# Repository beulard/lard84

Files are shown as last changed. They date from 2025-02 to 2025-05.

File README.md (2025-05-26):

# lard84

A custom 75% ansi low-profile keyboard.

- [PCB](#pcb)
- [Plate](#plate)
- [Case](#case)
- [Acknowledgments](#acknowledgments)
- [Extra pictures](#extra-pictures)

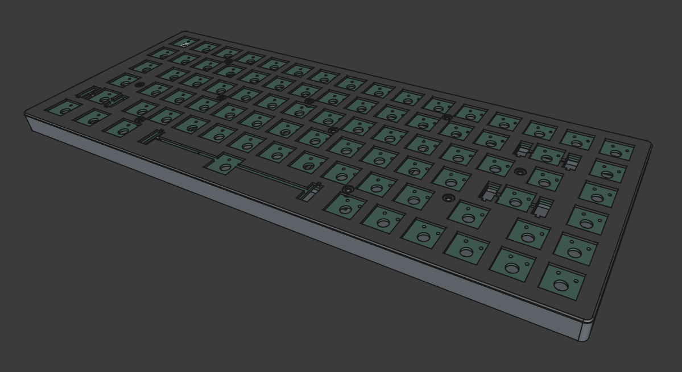
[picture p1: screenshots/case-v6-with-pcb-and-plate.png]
Case, PCB and plate assembled


The assembly is done in (sort of) [sandwich mount style](https://thomasbaart.nl/2019/04/07/cheat-sheet-custom-keyboard-mounting-styles/).
Compared to sandwich mount, there is no top frame (the plate sits at the top), and
it is screwed into the case's mounting posts from above.

Here it is finally assembled:
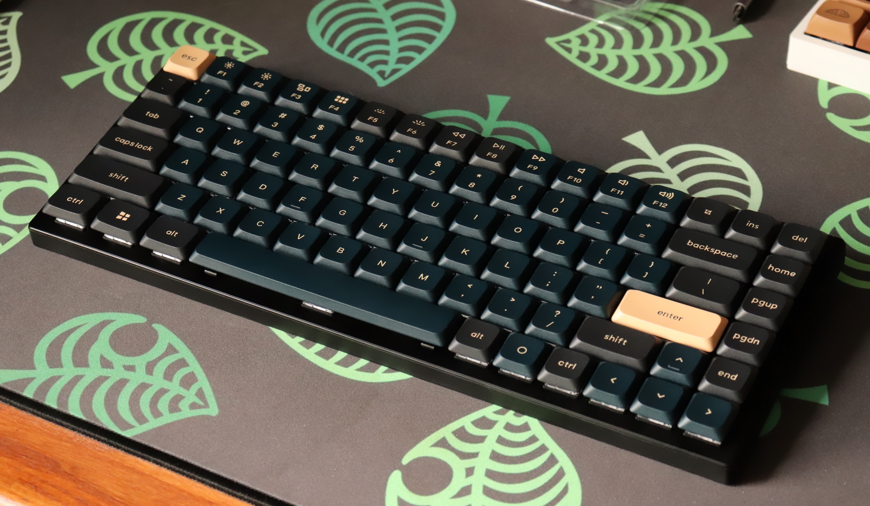
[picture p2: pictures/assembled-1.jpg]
The lard84 fully assembled


## PCB

The PCB (lard84.kicad_pro) is an 84-key design based on the [RP2350 Stamp](https://lectronz.com/products/rp2350-stamp), made using KiCad 8.0.
It is entirely hand-solderable (smallest footprint is 0603).

The design features a micro-usb port, full n-key rollover using a diode for each switch, a status LED, and apparent debug pins for development.

Key placement follows an [ANSI 75% layout](https://docs.keebd.com/information/keyboard-layouts#75-ansi).

The design supports [Gateron KS-33 low-profile switches](https://www.gateron.co/products/gateron-low-profile-mechanical-switch-set), and features holes
for the associated [low-profile stabilizers](https://www.gateron.com/products/gateron-low-profile-plate-mounted-stabilizer).

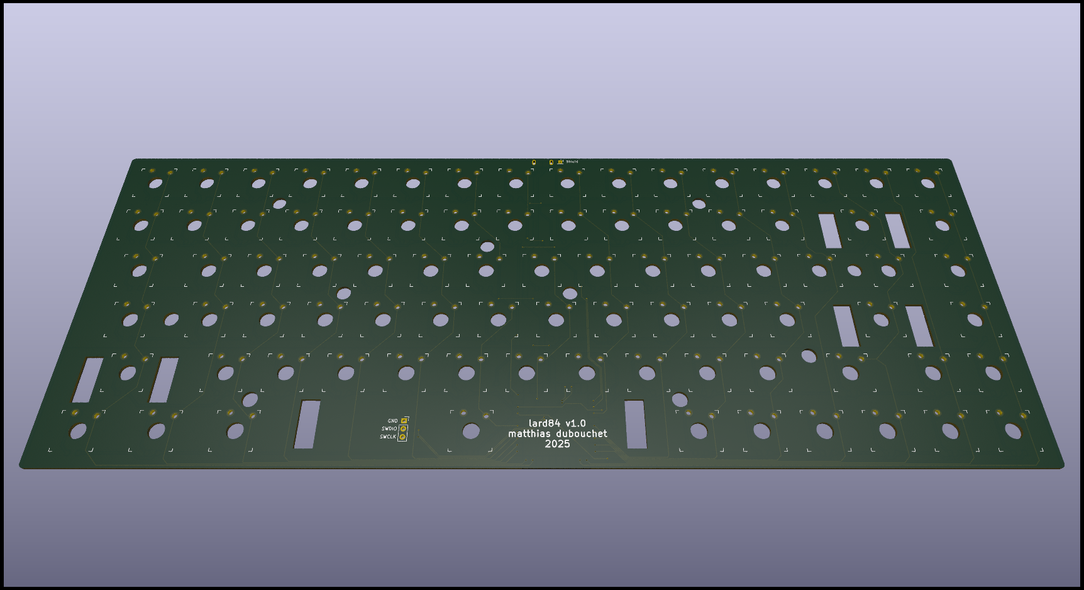
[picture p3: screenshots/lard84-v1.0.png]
A screenshot of the PCB in KiCad

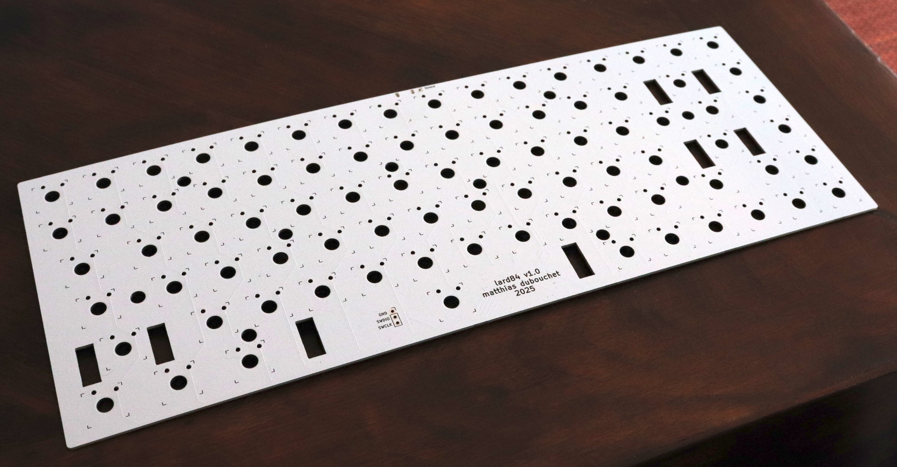
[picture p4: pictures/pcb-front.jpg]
PCB irl


## Plate

The top plate (plate v38.f3z) supports the switches, adds rigidity and gives a nice finish. It was made in Fusion360.

It is a relatively simple design with a square cutout for each key, two extra cutouts around the Backspace, Space, Enter and LShift keys
for their plate-mounted stabilizers, and 10 mounting holes for screws.

One key challenge was to figure out the placement and shape for the stabilizer cutouts, because of insufficient information on
the datasheets from the manufacturer.

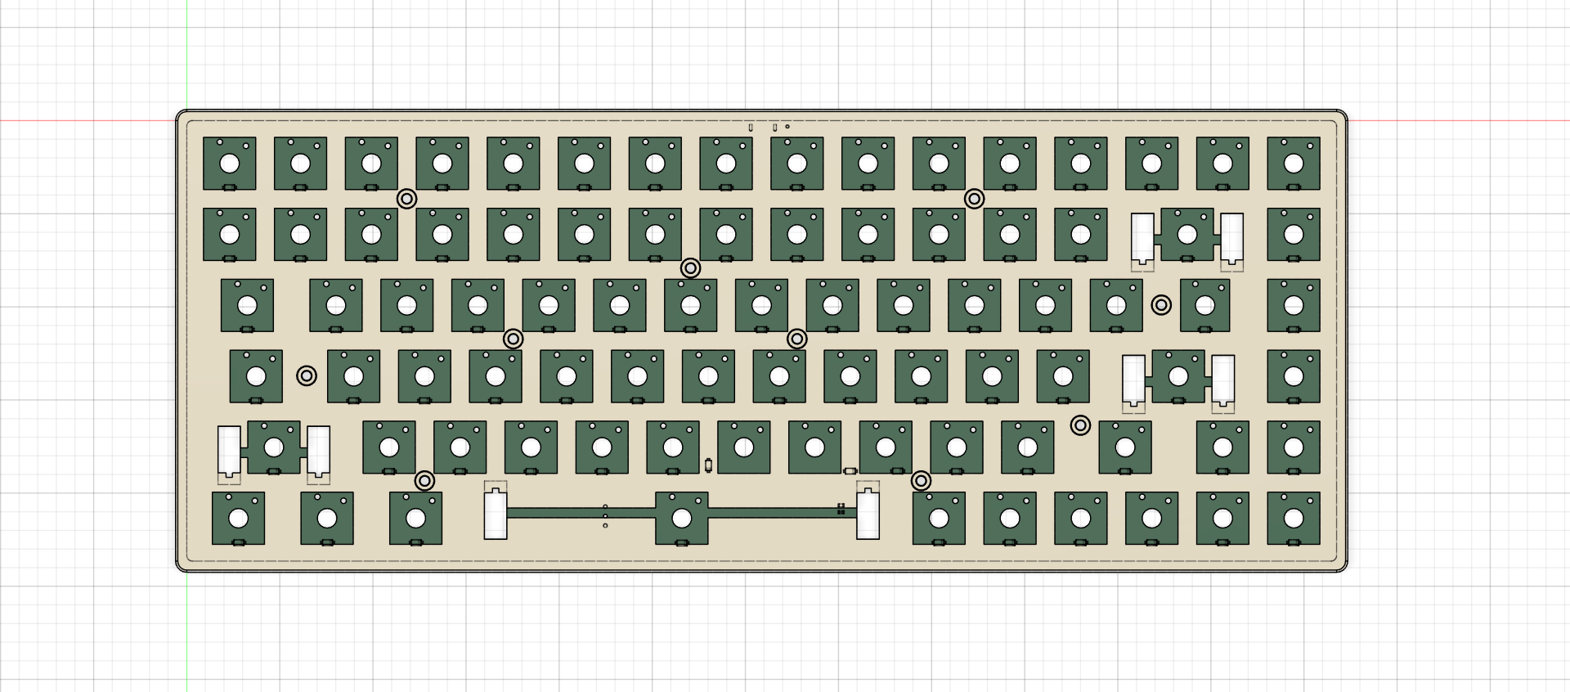
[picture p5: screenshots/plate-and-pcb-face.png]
Plate in Fusion360

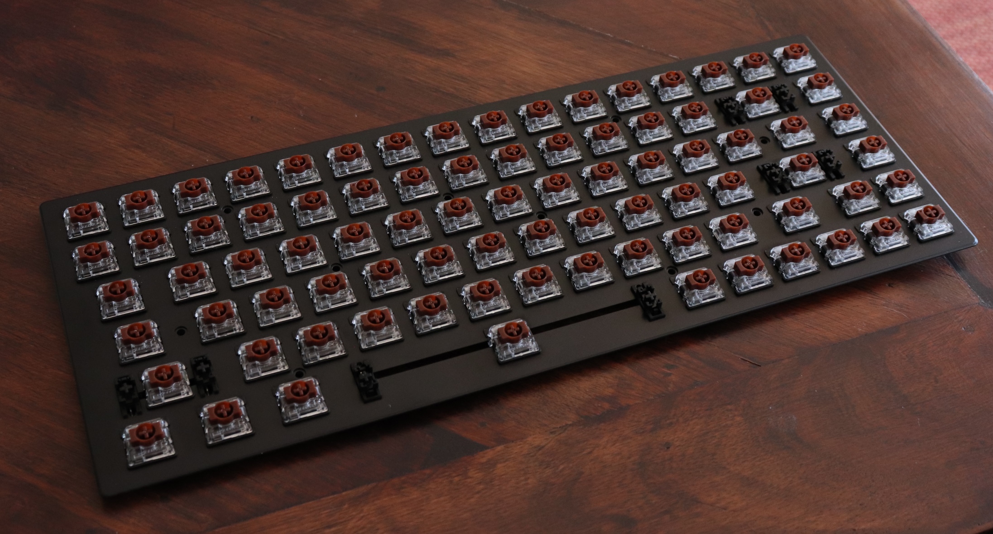
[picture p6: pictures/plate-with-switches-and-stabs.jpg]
Plate irl


## Case

The case (case.FCStd) is a 3D-printable plastic enclosing and two feet for a more comfortable typing angle.

The enclosing features mounting posts for the PCB and plate, and anti-warping structural elements.

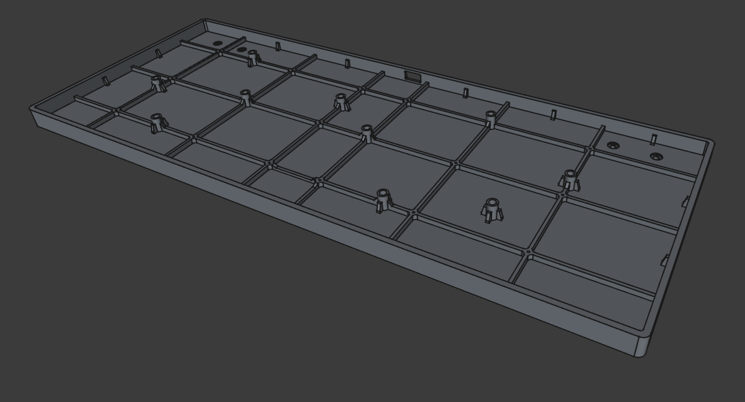
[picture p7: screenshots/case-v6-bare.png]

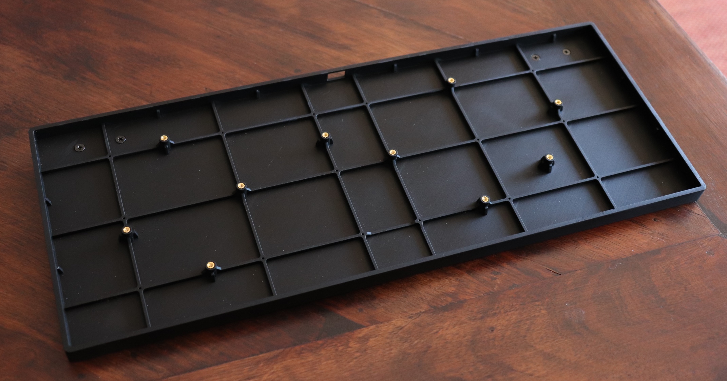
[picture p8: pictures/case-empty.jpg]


## Acknowledgments

Thanks to these open source repos for providing vital KiCad symbol/footprint libraries.
- [RP2350 Stamp](https://github.com/solderparty/rp2xxx_stamp_footprints)
- [Gateron switches](https://github.com/siderakb/key-switches.pretty)

## Extra pictures

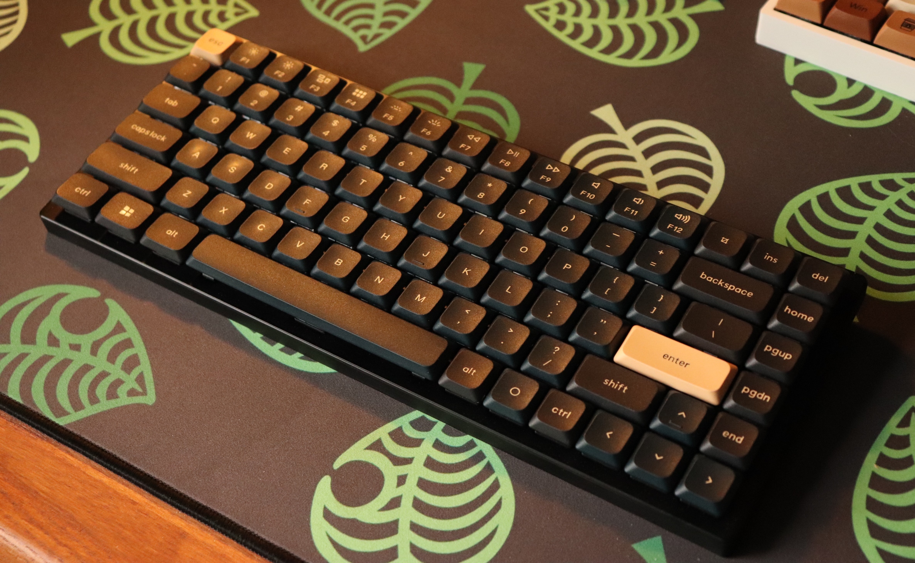
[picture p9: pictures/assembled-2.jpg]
Another assembled pic

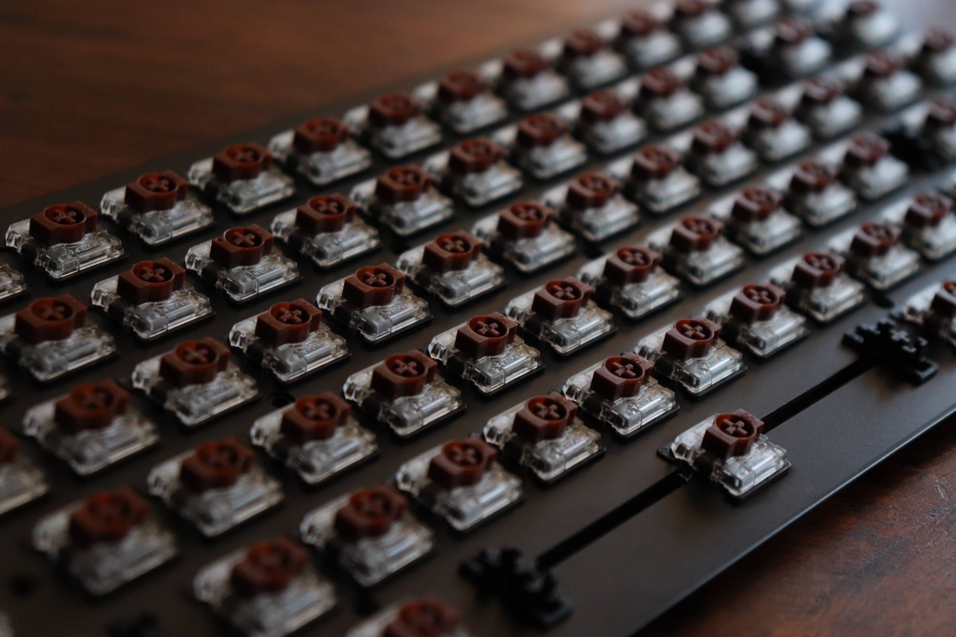
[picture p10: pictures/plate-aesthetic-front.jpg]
Front of plates

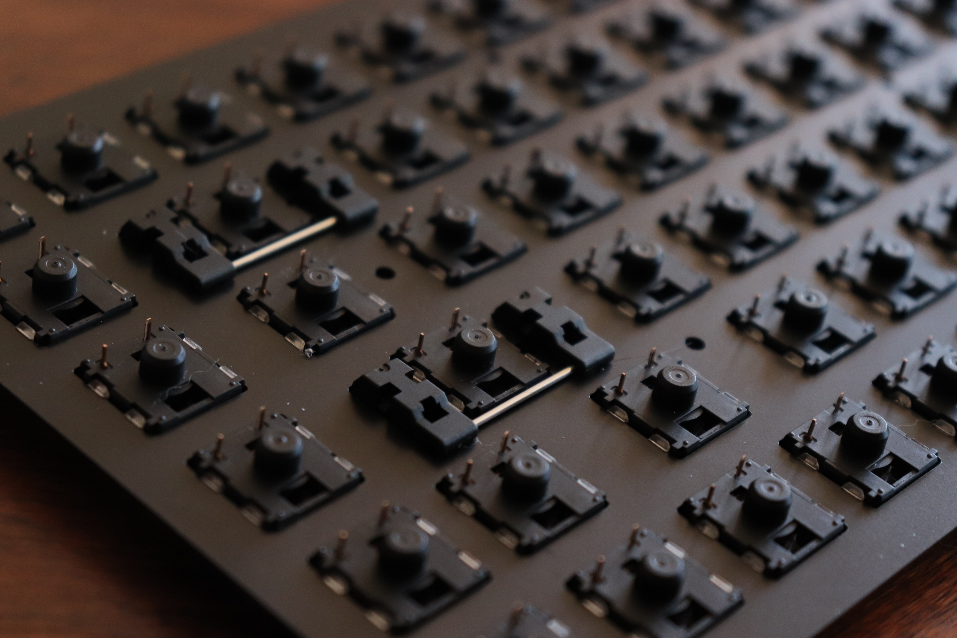
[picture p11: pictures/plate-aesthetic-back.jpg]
Back of plate

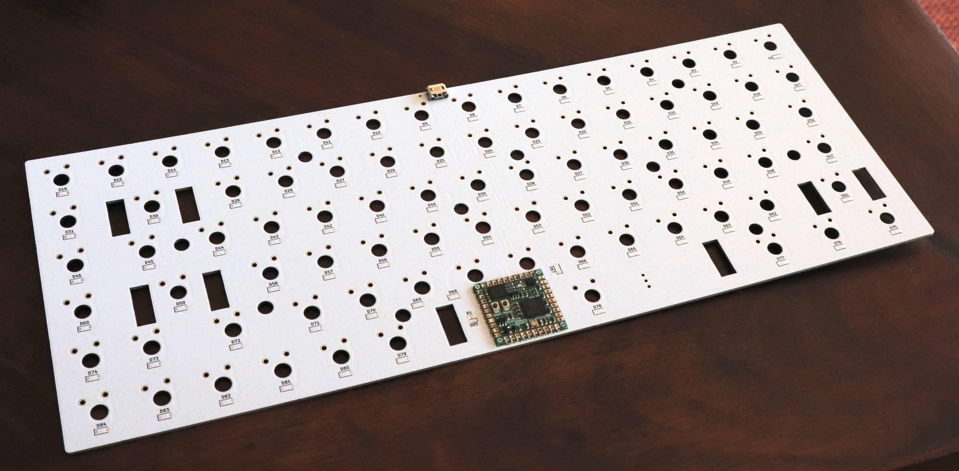
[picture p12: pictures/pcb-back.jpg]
PCB back

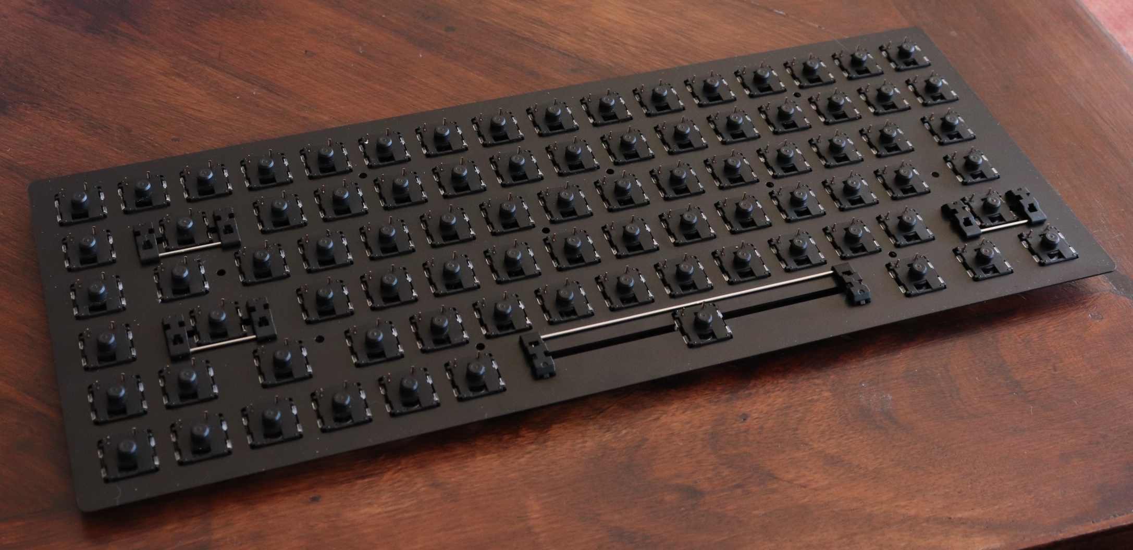
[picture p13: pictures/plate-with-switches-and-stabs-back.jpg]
Plate back

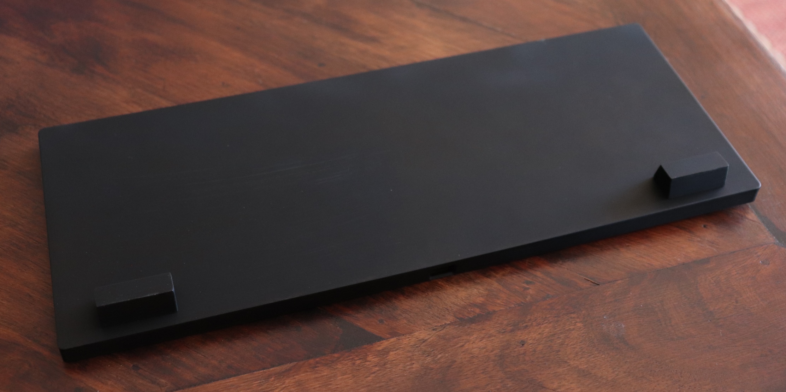
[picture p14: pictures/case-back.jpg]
Back of case with feet


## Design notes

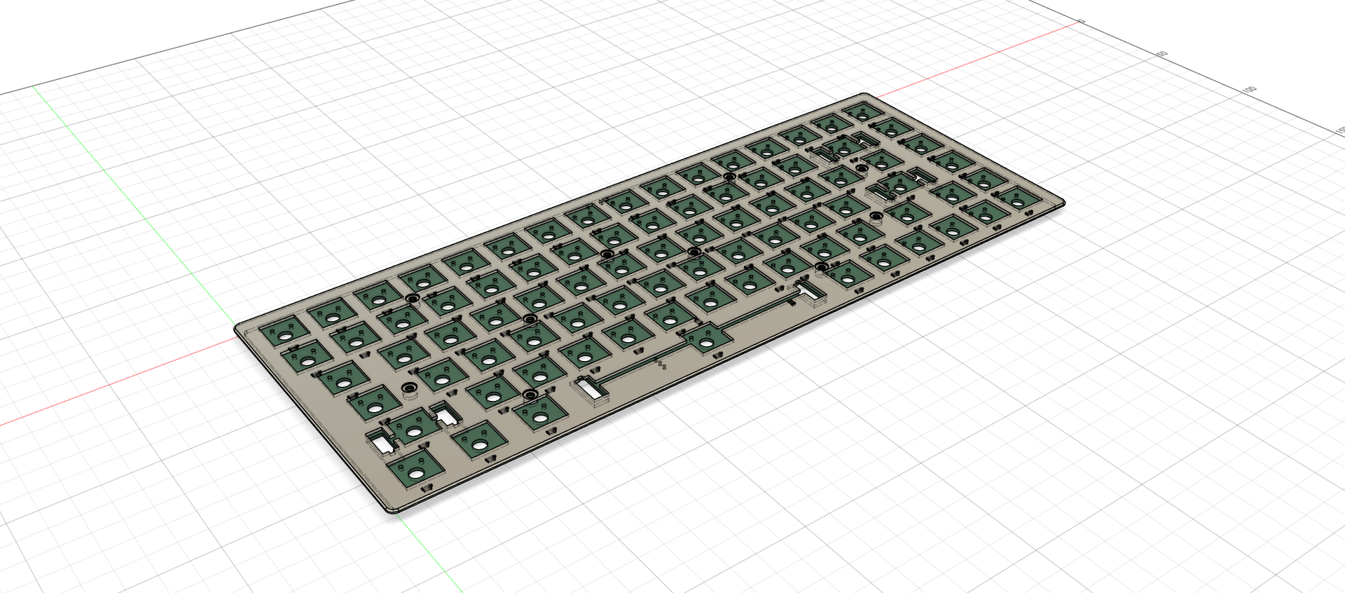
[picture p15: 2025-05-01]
screenshots/plate-and-pcb.png

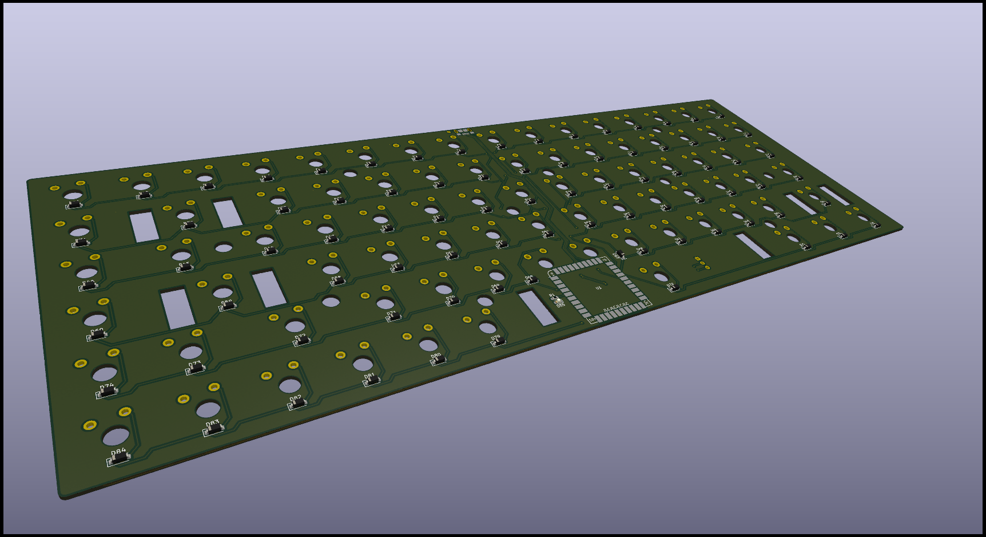
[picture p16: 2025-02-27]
screenshots/lard84-v1.0-angle-back.png

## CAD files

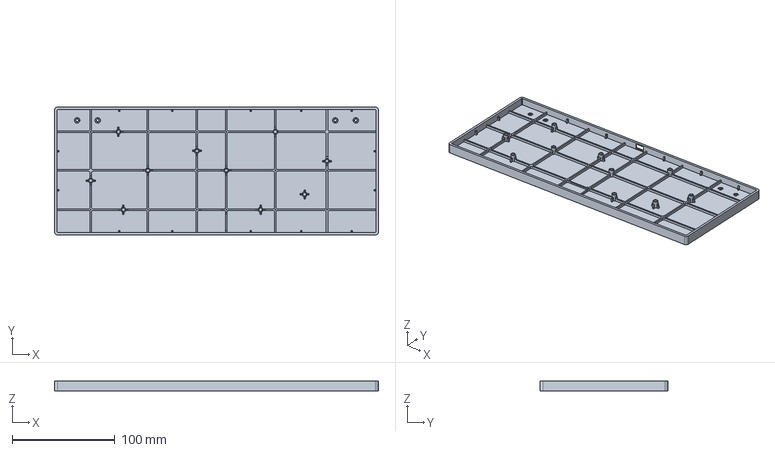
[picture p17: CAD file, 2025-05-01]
case.FCStd
314.7 x 124.3 x 10.0 mm

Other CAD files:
plate v38.f3z

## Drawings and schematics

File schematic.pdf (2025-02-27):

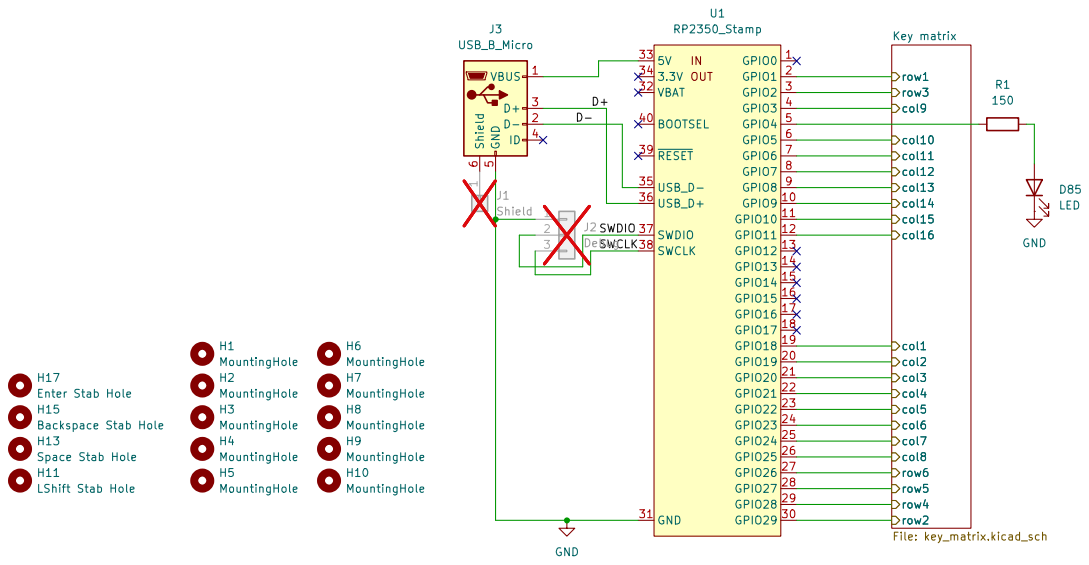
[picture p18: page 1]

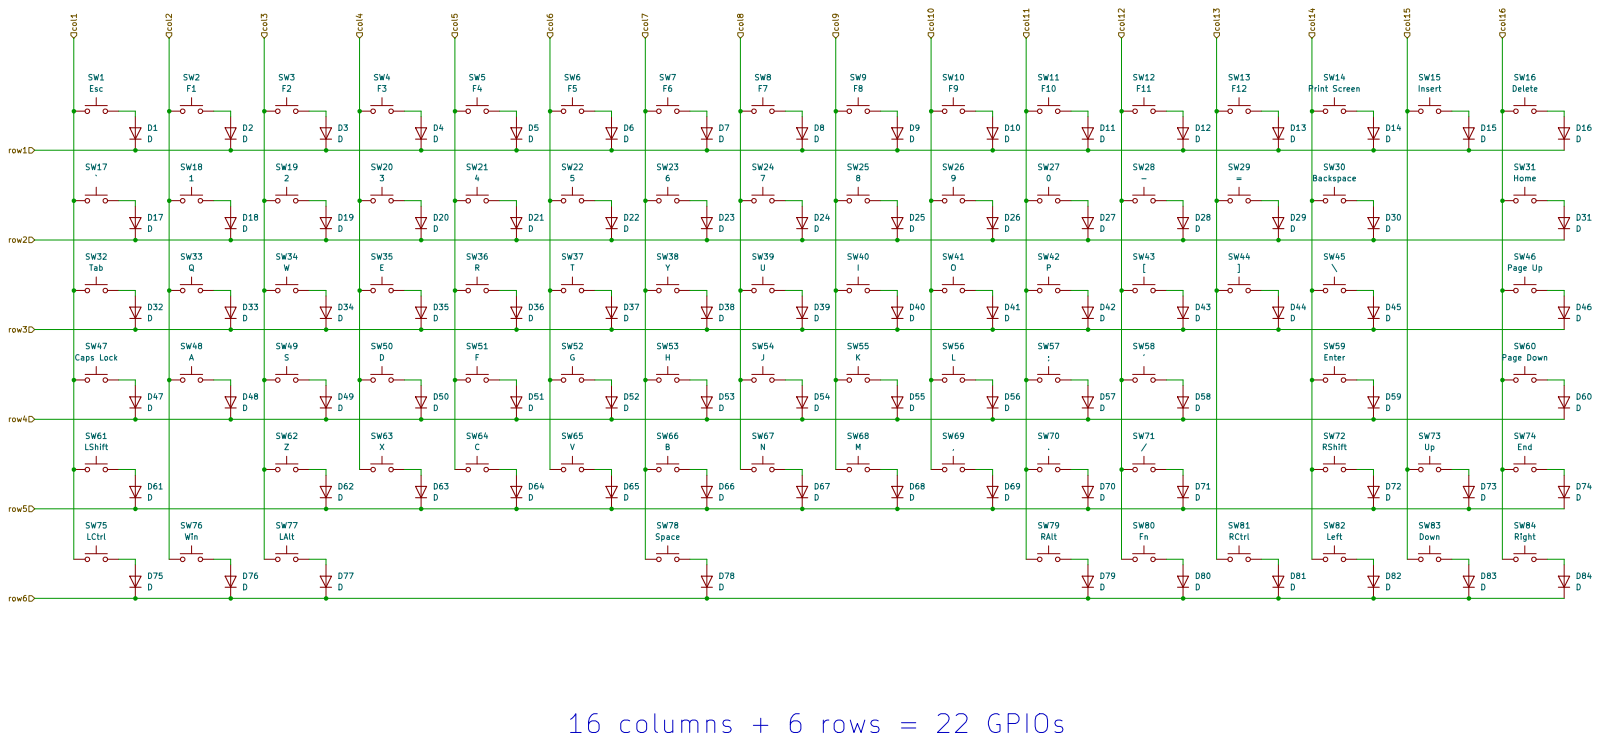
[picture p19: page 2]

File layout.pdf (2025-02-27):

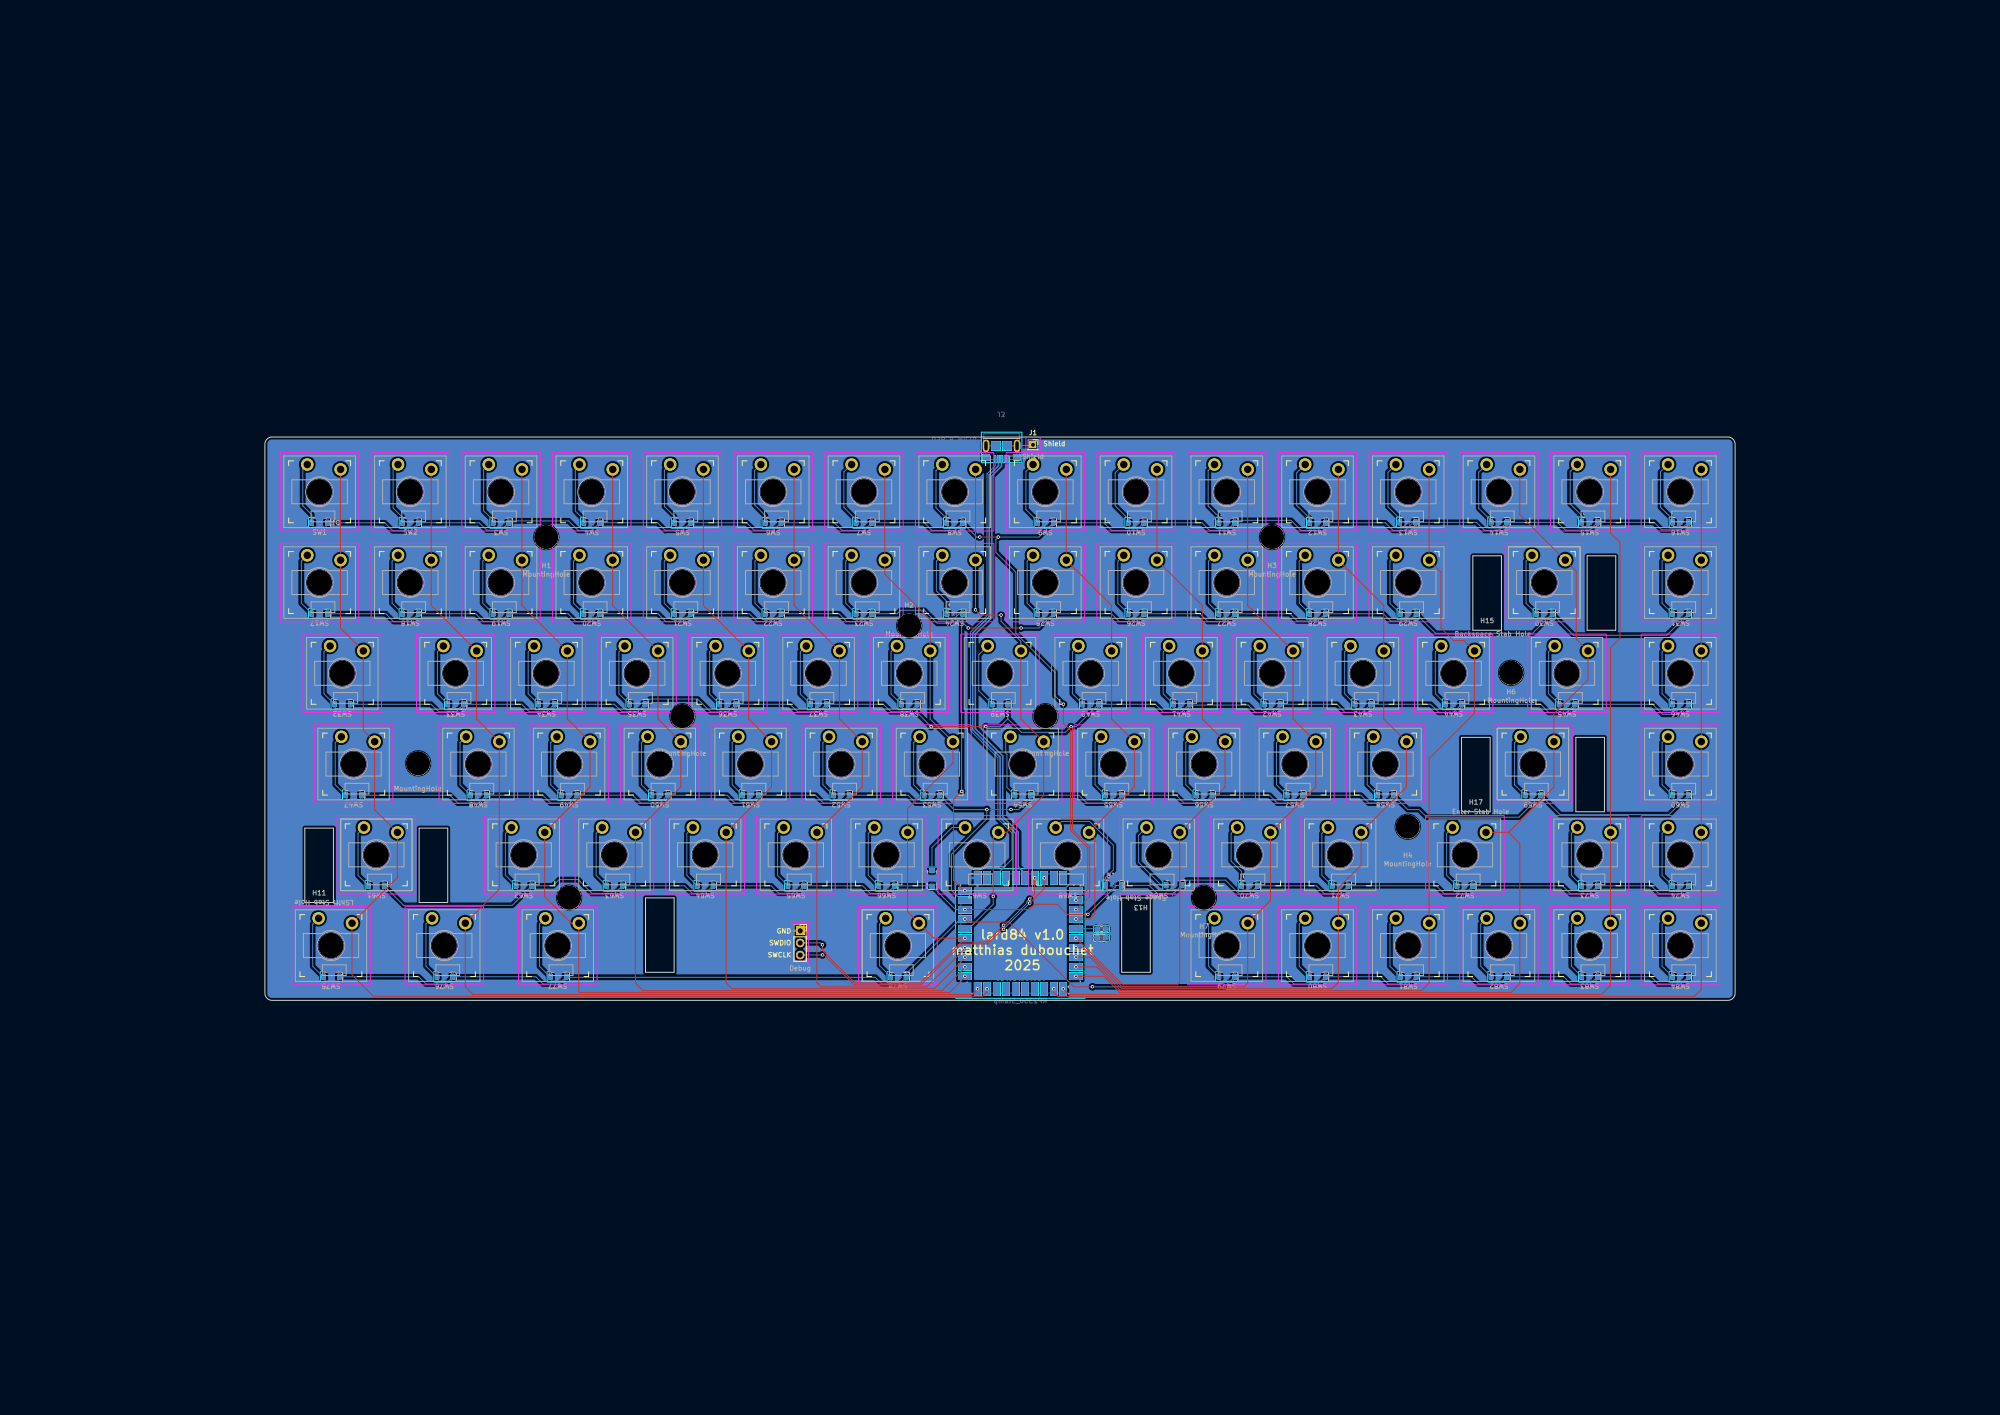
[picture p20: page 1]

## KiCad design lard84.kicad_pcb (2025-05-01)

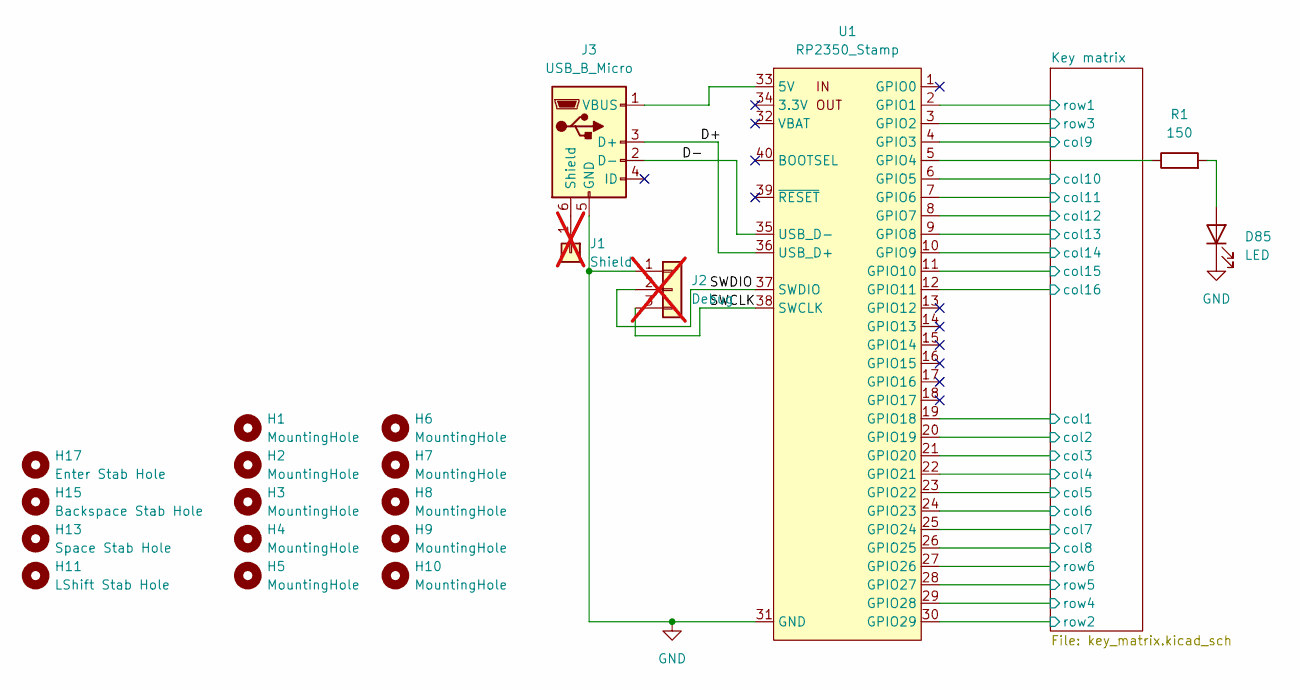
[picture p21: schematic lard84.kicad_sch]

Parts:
D85: LED; LED_0603_1608Metric_Pad1.05x0.95mm_HandSolder
H1, H2, H3, H4, H5, H6, H7, H8, H9, H10: MountingHole; Stand hole 5mm
H11: LShift Stab Hole; Gateron low-profile 2U stabilizer
H13: Space Stab Hole; Gateron low-profile 6.25U stabilizer
H15: Backspace Stab Hole; Gateron low-profile 2U stabilizer
H17: Enter Stab Hole; Gateron low-profile 2U stabilizer
J1: Shield; PinSocket_1x01_P2.00mm_Vertical; not fitted
J2: Debug; PinSocket_1x03_P2.54mm_Vertical; not fitted
J3: USB_B_Micro; CONN5_2013499-1_TEC
R1: 150; R_0603_1608Metric_Pad0.98x0.95mm_HandSolder
U1: RP2350_Stamp; RP2xxx_Stamp_SMD

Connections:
/D+: J3.3 (D+), U1.36 (USB_D+)
/D-: J3.2 (D-), U1.35 (USB_D-)
/Key matrix/col1: U1.19 (GPIO18); also elsewhere on the board
/Key matrix/col2: U1.20 (GPIO19); also elsewhere on the board
/Key matrix/col3: U1.21 (GPIO20); also elsewhere on the board
/Key matrix/col4: U1.22 (GPIO21); also elsewhere on the board
/Key matrix/col5: U1.23 (GPIO22); also elsewhere on the board
/Key matrix/col6: U1.24 (GPIO23); also elsewhere on the board
/Key matrix/col7: U1.25 (GPIO24); also elsewhere on the board
/Key matrix/col8: U1.26 (GPIO25); also elsewhere on the board
/Key matrix/col9: U1.4 (GPIO3); also elsewhere on the board
/Key matrix/col10: U1.6 (GPIO5); also elsewhere on the board
/Key matrix/col11: U1.7 (GPIO6); also elsewhere on the board
/Key matrix/col12: U1.8 (GPIO7); also elsewhere on the board
/Key matrix/col13: U1.9 (GPIO8); also elsewhere on the board
/Key matrix/col14: U1.10 (GPIO9); also elsewhere on the board
/Key matrix/col15: U1.11 (GPIO10); also elsewhere on the board
/Key matrix/col16: U1.12 (GPIO11); also elsewhere on the board
/Key matrix/row1: U1.2 (GPIO1); also elsewhere on the board
/Key matrix/row2: U1.30 (GPIO29); also elsewhere on the board
/Key matrix/row3: U1.3 (GPIO2); also elsewhere on the board
/Key matrix/row4: U1.29 (GPIO28); also elsewhere on the board
/Key matrix/row5: U1.28 (GPIO27); also elsewhere on the board
/Key matrix/row6: U1.27 (GPIO26); also elsewhere on the board
/SWCLK: J2.3, U1.38 (SWCLK)
/SWDIO: J2.2, U1.37 (SWDIO)
GND: D85.1 (K), J2.1, J3.5 (GND), U1.31 (GND)
unnamed: D85.2 (A), R1.2
unnamed: J1.1, J3.6 (Shield)
unnamed: J3.1 (VBUS), U1.33 (5V)
unnamed: R1.1, U1.5 (GPIO4)

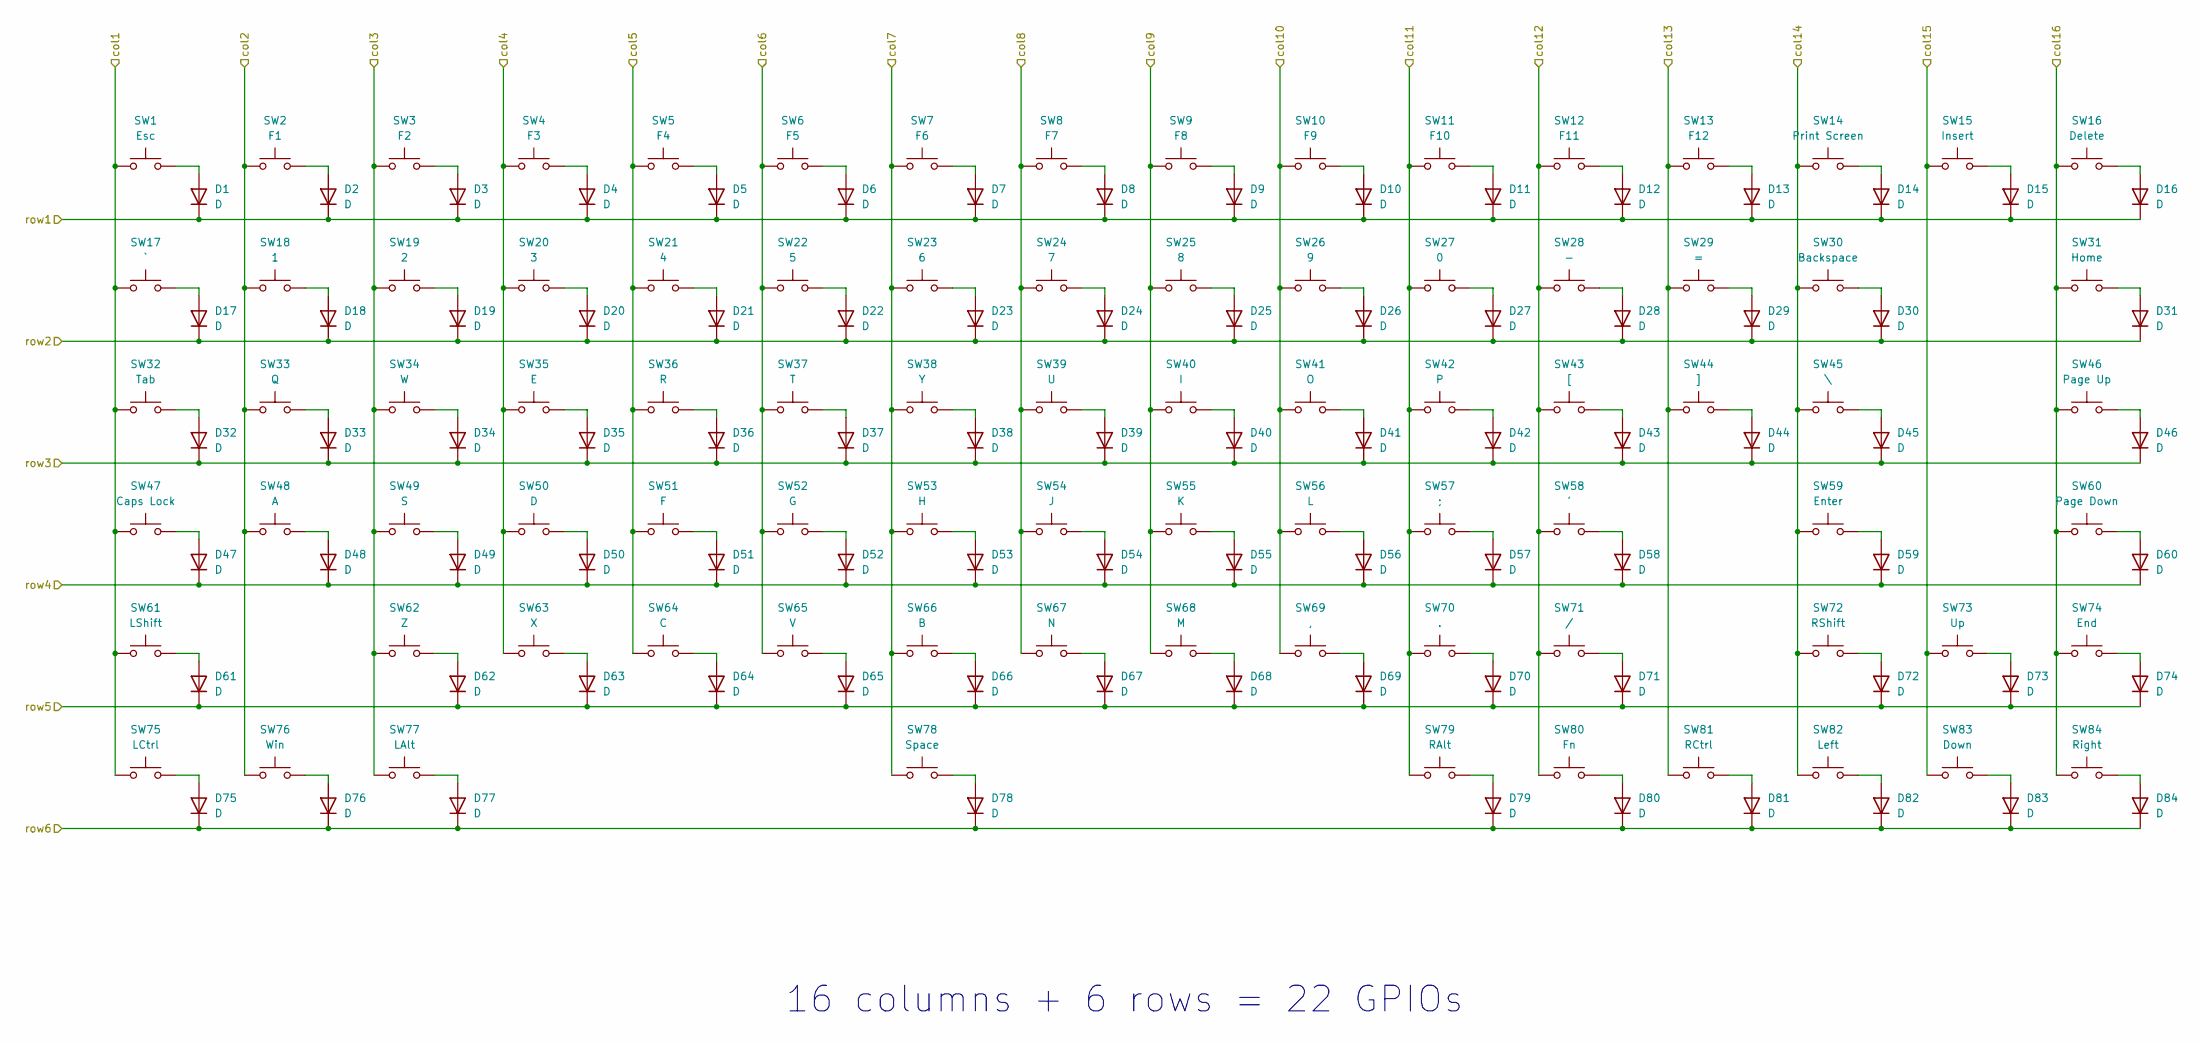
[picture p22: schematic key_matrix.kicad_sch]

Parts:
D1, D2, D3, D4, D5, D6, D7, D8, D9, D10, D11, D12, D13, D14, D15, D16, D17, D18, D19, D20, D21, D22, D23, D24, D25, D26, D27, D28, D29, D30, D31, D32, D33, D34, D35, D36, D37, D38, D39, D40, D41, D42, D43, D44, D45, D46, D47, D48, D49, D50, D51, D52, D53, D54, D55, D56, D57, D58, D59, D60, D61, D62, D63, D64, D65, D66, D67, D68, D69, D70, D71, D72, D73, D74, D75, D76, D77, D78, D79, D80, D81, D82, D83, D84: D; D_SOD-123
SW1: Esc; SW_Gateron_LowProfile_THT
SW2: F1; SW_Gateron_LowProfile_THT
SW3: F2; SW_Gateron_LowProfile_THT
SW4: F3; SW_Gateron_LowProfile_THT
SW5: F4; SW_Gateron_LowProfile_THT
SW6: F5; SW_Gateron_LowProfile_THT
SW7: F6; SW_Gateron_LowProfile_THT
SW8: F7; SW_Gateron_LowProfile_THT
SW9: F8; SW_Gateron_LowProfile_THT
SW10: F9; SW_Gateron_LowProfile_THT
SW11: F10; SW_Gateron_LowProfile_THT
SW12: F11; SW_Gateron_LowProfile_THT
SW13: F12; SW_Gateron_LowProfile_THT
SW14: Print Screen; SW_Gateron_LowProfile_THT
SW15: Insert; SW_Gateron_LowProfile_THT
SW16: Delete; SW_Gateron_LowProfile_THT
SW17: `; SW_Gateron_LowProfile_THT
SW18: 1; SW_Gateron_LowProfile_THT
SW19: 2; SW_Gateron_LowProfile_THT
SW20: 3; SW_Gateron_LowProfile_THT
SW21: 4; SW_Gateron_LowProfile_THT
SW22: 5; SW_Gateron_LowProfile_THT
SW23: 6; SW_Gateron_LowProfile_THT
SW24: 7; SW_Gateron_LowProfile_THT
SW25: 8; SW_Gateron_LowProfile_THT
SW26: 9; SW_Gateron_LowProfile_THT
SW27: 0; SW_Gateron_LowProfile_THT
SW28: -; SW_Gateron_LowProfile_THT
SW29: =; SW_Gateron_LowProfile_THT
SW30: Backspace; SW_Gateron_LowProfile_THT
SW31: Home; SW_Gateron_LowProfile_THT
SW32: Tab; SW_Gateron_LowProfile_THT
SW33: Q; SW_Gateron_LowProfile_THT
SW34: W; SW_Gateron_LowProfile_THT
SW35: E; SW_Gateron_LowProfile_THT
SW36: R; SW_Gateron_LowProfile_THT
SW37: T; SW_Gateron_LowProfile_THT
SW38: Y; SW_Gateron_LowProfile_THT
SW39: U; SW_Gateron_LowProfile_THT
SW40: I; SW_Gateron_LowProfile_THT
SW41: O; SW_Gateron_LowProfile_THT
SW42: P; SW_Gateron_LowProfile_THT
SW43: [; SW_Gateron_LowProfile_THT
SW44: ]; SW_Gateron_LowProfile_THT
SW45: \; SW_Gateron_LowProfile_THT
SW46: Page Up; SW_Gateron_LowProfile_THT
SW47: Caps Lock; SW_Gateron_LowProfile_THT
SW48: A; SW_Gateron_LowProfile_THT
SW49: S; SW_Gateron_LowProfile_THT
SW50: D; SW_Gateron_LowProfile_THT
SW51: F; SW_Gateron_LowProfile_THT
SW52: G; SW_Gateron_LowProfile_THT
SW53: H; SW_Gateron_LowProfile_THT
SW54: J; SW_Gateron_LowProfile_THT
SW55: K; SW_Gateron_LowProfile_THT
SW56: L; SW_Gateron_LowProfile_THT
SW57: ;; SW_Gateron_LowProfile_THT
SW58: '; SW_Gateron_LowProfile_THT
SW59: Enter; SW_Gateron_LowProfile_THT
SW60: Page Down; SW_Gateron_LowProfile_THT
SW61: LShift; SW_Gateron_LowProfile_THT
SW62: Z; SW_Gateron_LowProfile_THT
SW63: X; SW_Gateron_LowProfile_THT
SW64: C; SW_Gateron_LowProfile_THT
SW65: V; SW_Gateron_LowProfile_THT
SW66: B; SW_Gateron_LowProfile_THT
SW67: N; SW_Gateron_LowProfile_THT
SW68: M; SW_Gateron_LowProfile_THT
SW69: ,; SW_Gateron_LowProfile_THT
SW70: .; SW_Gateron_LowProfile_THT
SW71: /; SW_Gateron_LowProfile_THT
SW72: RShift; SW_Gateron_LowProfile_THT
SW73: Up; SW_Gateron_LowProfile_THT
SW74: End; SW_Gateron_LowProfile_THT
SW75: LCtrl; SW_Gateron_LowProfile_THT
SW76: Win; SW_Gateron_LowProfile_THT
SW77: LAlt; SW_Gateron_LowProfile_THT
SW78: Space; SW_Gateron_LowProfile_THT
SW79: RAlt; SW_Gateron_LowProfile_THT
SW80: Fn; SW_Gateron_LowProfile_THT
SW81: RCtrl; SW_Gateron_LowProfile_THT
SW82: Left; SW_Gateron_LowProfile_THT
SW83: Down; SW_Gateron_LowProfile_THT
SW84: Right; SW_Gateron_LowProfile_THT

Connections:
/Key matrix/col1: SW1.1, SW17.1, SW32.1, SW47.1, SW61.1, SW75.1; also elsewhere on the board
/Key matrix/col2: SW2.1, SW18.1, SW33.1, SW48.1, SW76.1; also elsewhere on the board
/Key matrix/col3: SW3.1, SW19.1, SW34.1, SW49.1, SW62.1, SW77.1; also elsewhere on the board
/Key matrix/col4: SW4.1, SW20.1, SW35.1, SW50.1, SW63.1; also elsewhere on the board
/Key matrix/col5: SW5.1, SW21.1, SW36.1, SW51.1, SW64.1; also elsewhere on the board
/Key matrix/col6: SW6.1, SW22.1, SW37.1, SW52.1, SW65.1; also elsewhere on the board
/Key matrix/col7: SW7.1, SW23.1, SW38.1, SW53.1, SW66.1, SW78.1; also elsewhere on the board
/Key matrix/col8: SW8.1, SW24.1, SW39.1, SW54.1, SW67.1; also elsewhere on the board
/Key matrix/col9: SW9.1, SW25.1, SW40.1, SW55.1, SW68.1; also elsewhere on the board
/Key matrix/col10: SW10.1, SW26.1, SW41.1, SW56.1, SW69.1; also elsewhere on the board
/Key matrix/col11: SW11.1, SW27.1, SW42.1, SW57.1, SW70.1, SW79.1; also elsewhere on the board
/Key matrix/col12: SW12.1, SW28.1, SW43.1, SW58.1, SW71.1, SW80.1; also elsewhere on the board
/Key matrix/col13: SW13.1, SW29.1, SW44.1, SW81.1; also elsewhere on the board
/Key matrix/col14: SW14.1, SW30.1, SW45.1, SW59.1, SW72.1, SW82.1; also elsewhere on the board
/Key matrix/col15: SW15.1, SW73.1, SW83.1; also elsewhere on the board
/Key matrix/col16: SW16.1, SW31.1, SW46.1, SW60.1, SW74.1, SW84.1; also elsewhere on the board
/Key matrix/row1: D1.1 (K), D2.1 (K), D3.1 (K), D4.1 (K), D5.1 (K), D6.1 (K), D7.1 (K), D8.1 (K), D9.1 (K), D10.1 (K), D11.1 (K), D12.1 (K), D13.1 (K), D14.1 (K), D15.1 (K), D16.1 (K); also elsewhere on the board
/Key matrix/row2: D17.1 (K), D18.1 (K), D19.1 (K), D20.1 (K), D21.1 (K), D22.1 (K), D23.1 (K), D24.1 (K), D25.1 (K), D26.1 (K), D27.1 (K), D28.1 (K), D29.1 (K), D30.1 (K), D31.1 (K); also elsewhere on the board
/Key matrix/row3: D32.1 (K), D33.1 (K), D34.1 (K), D35.1 (K), D36.1 (K), D37.1 (K), D38.1 (K), D39.1 (K), D40.1 (K), D41.1 (K), D42.1 (K), D43.1 (K), D44.1 (K), D45.1 (K), D46.1 (K); also elsewhere on the board
/Key matrix/row4: D47.1 (K), D48.1 (K), D49.1 (K), D50.1 (K), D51.1 (K), D52.1 (K), D53.1 (K), D54.1 (K), D55.1 (K), D56.1 (K), D57.1 (K), D58.1 (K), D59.1 (K), D60.1 (K); also elsewhere on the board
/Key matrix/row5: D61.1 (K), D62.1 (K), D63.1 (K), D64.1 (K), D65.1 (K), D66.1 (K), D67.1 (K), D68.1 (K), D69.1 (K), D70.1 (K), D71.1 (K), D72.1 (K), D73.1 (K), D74.1 (K); also elsewhere on the board
/Key matrix/row6: D75.1 (K), D76.1 (K), D77.1 (K), D78.1 (K), D79.1 (K), D80.1 (K), D81.1 (K), D82.1 (K), D83.1 (K), D84.1 (K); also elsewhere on the board
unnamed: D1.2 (A), SW1.2
unnamed: D2.2 (A), SW2.2
unnamed: D3.2 (A), SW3.2
unnamed: D4.2 (A), SW4.2
unnamed: D5.2 (A), SW5.2
unnamed: D6.2 (A), SW6.2
unnamed: D7.2 (A), SW7.2
unnamed: D8.2 (A), SW8.2
unnamed: D9.2 (A), SW9.2
unnamed: D10.2 (A), SW10.2
unnamed: D11.2 (A), SW11.2
unnamed: D12.2 (A), SW12.2
unnamed: D13.2 (A), SW13.2
unnamed: D14.2 (A), SW14.2
unnamed: D15.2 (A), SW15.2
unnamed: D16.2 (A), SW16.2
unnamed: D17.2 (A), SW17.2
unnamed: D18.2 (A), SW18.2
unnamed: D19.2 (A), SW19.2
unnamed: D20.2 (A), SW20.2
unnamed: D21.2 (A), SW21.2
unnamed: D22.2 (A), SW22.2
unnamed: D23.2 (A), SW23.2
unnamed: D24.2 (A), SW24.2
unnamed: D25.2 (A), SW25.2
unnamed: D26.2 (A), SW26.2
unnamed: D27.2 (A), SW27.2
unnamed: D28.2 (A), SW28.2
unnamed: D29.2 (A), SW29.2
unnamed: D30.2 (A), SW30.2
unnamed: D31.2 (A), SW31.2
unnamed: D32.2 (A), SW32.2
unnamed: D33.2 (A), SW33.2
unnamed: D34.2 (A), SW34.2
unnamed: D35.2 (A), SW35.2
unnamed: D36.2 (A), SW36.2
unnamed: D37.2 (A), SW37.2
unnamed: D38.2 (A), SW38.2
unnamed: D39.2 (A), SW39.2
unnamed: D40.2 (A), SW40.2
unnamed: D41.2 (A), SW41.2
unnamed: D42.2 (A), SW42.2
unnamed: D43.2 (A), SW43.2
unnamed: D44.2 (A), SW44.2
unnamed: D45.2 (A), SW45.2
unnamed: D46.2 (A), SW46.2
unnamed: D47.2 (A), SW47.2
unnamed: D48.2 (A), SW48.2
unnamed: D49.2 (A), SW49.2
unnamed: D50.2 (A), SW50.2
unnamed: D51.2 (A), SW51.2
unnamed: D52.2 (A), SW52.2
unnamed: D53.2 (A), SW53.2
unnamed: D54.2 (A), SW54.2
unnamed: D55.2 (A), SW55.2
unnamed: D56.2 (A), SW56.2
unnamed: D57.2 (A), SW57.2
unnamed: D58.2 (A), SW58.2
unnamed: D59.2 (A), SW59.2
unnamed: D60.2 (A), SW60.2
unnamed: D61.2 (A), SW61.2
unnamed: D62.2 (A), SW62.2
unnamed: D63.2 (A), SW63.2
unnamed: D64.2 (A), SW64.2
unnamed: D65.2 (A), SW65.2
unnamed: D66.2 (A), SW66.2
unnamed: D67.2 (A), SW67.2
unnamed: D68.2 (A), SW68.2
unnamed: D69.2 (A), SW69.2
unnamed: D70.2 (A), SW70.2
unnamed: D71.2 (A), SW71.2
unnamed: D72.2 (A), SW72.2
unnamed: D73.2 (A), SW73.2
unnamed: D74.2 (A), SW74.2
unnamed: D75.2 (A), SW75.2
unnamed: D76.2 (A), SW76.2
unnamed: D77.2 (A), SW77.2
unnamed: D78.2 (A), SW78.2
unnamed: D79.2 (A), SW79.2
unnamed: D80.2 (A), SW80.2
unnamed: D81.2 (A), SW81.2
unnamed: D82.2 (A), SW82.2
unnamed: D83.2 (A), SW83.2
unnamed: D84.2 (A), SW84.2

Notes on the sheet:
16 columns + 6 rows = 22 GPIOs

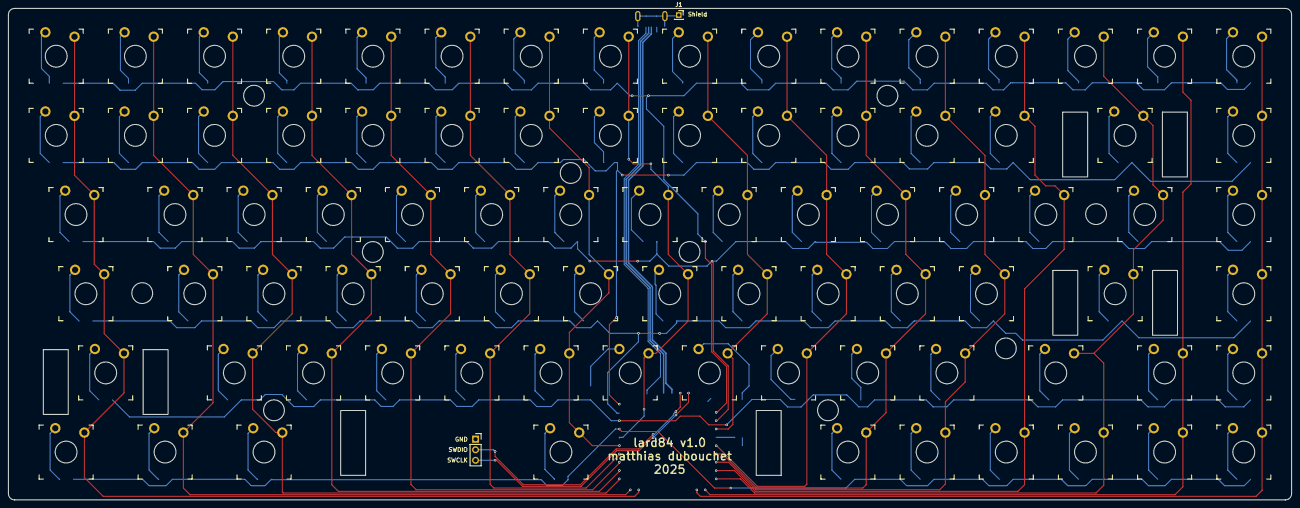
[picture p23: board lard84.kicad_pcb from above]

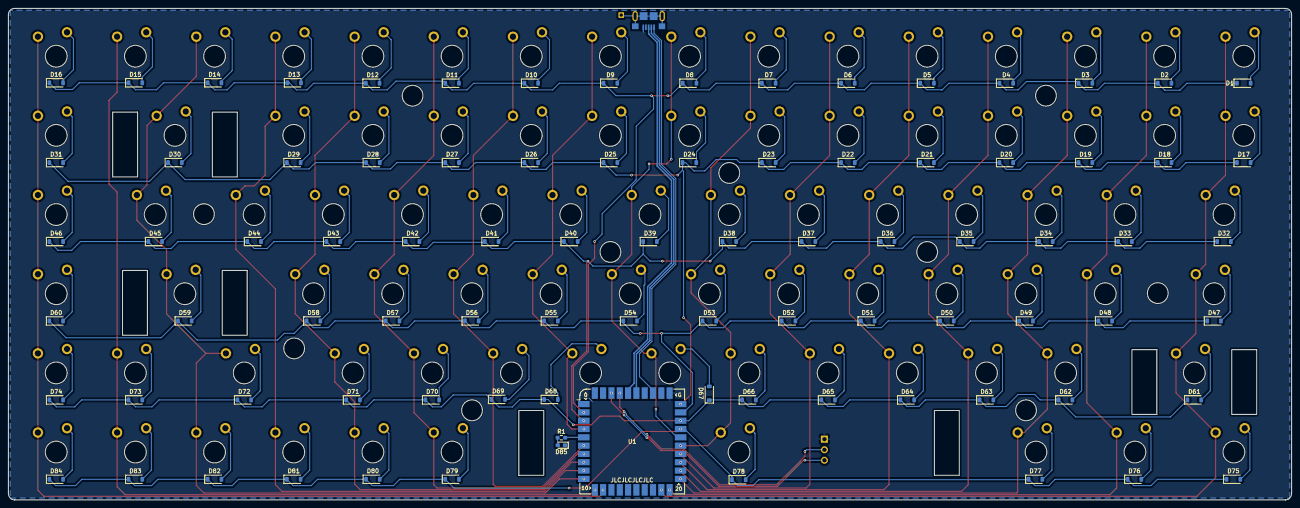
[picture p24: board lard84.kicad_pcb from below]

Board: 2 copper layers, 308.8 x 118.2 mm, 188 parts (88 on the bottom side), 115 nets.

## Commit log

2025-02-27 Add KiCad project files
    [lard84.kicad_pcb, lard84.kicad_sch]
2025-02-27 Schematic printout
2025-02-27 PCB layout printout
2025-05-01 Fix missing keymatrix schematic
    [key_matrix.kicad_sch, lard84.kicad_pcb]
2025-05-01 Add plate, case screenshots
2025-05-01 Add case source file
    [case.FCStd]
2025-05-01 Add plate and case info
2025-05-01 Add plate source file
    [plate v38.f3z]
2025-05-26 Add assembled pics
